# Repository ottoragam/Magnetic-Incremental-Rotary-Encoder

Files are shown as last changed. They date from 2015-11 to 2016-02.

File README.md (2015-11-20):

# Magnetic-Incremental-Rotary-Encoder

----------------------------------------------------------------------
Magnetic Incremental Rotary Encoder (c) by Gino Magarotto

Magnetic Incremental Rotary Encoder is licensed under a
Creative Commons Attribution-ShareAlike 3.0 Unported License.

You should have received a copy of the license along with this
work.  If not, see <http://creativecommons.org/licenses/by-sa/3.0/>.

----------------------------------------------------------------------

This project aims to provide a compact, easy to use, relatively high resolution and arguably cheap encoder. It uses the AS5040 magnetic rotary encoder IC from Austria Microsystems.

Project log on https://hackaday.io/project/8418-magnetic-incremental-rotary-encoder

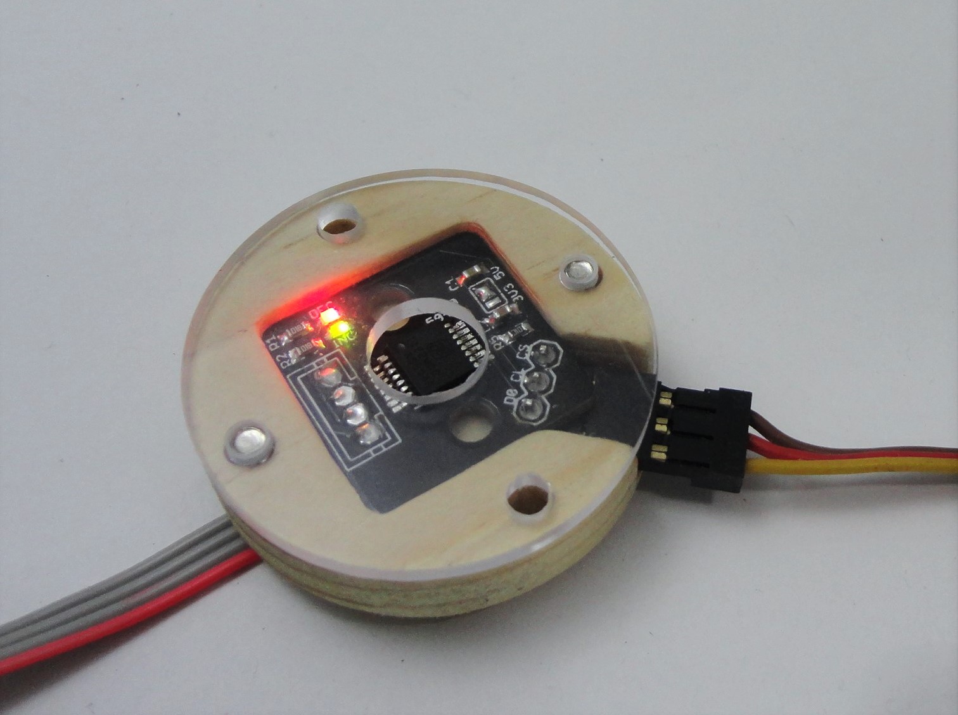
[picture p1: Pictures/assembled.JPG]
assembled


Included are.stl and .step files for the case, and .sch and .brd for the PCB.

The PCB is double sided and measures 20 x 20 mm. It could be home etched or manufactured using some low cost prototyping service. The case is designed to be milled, 3D printed or laser cut (the top part). A 3 mm or 1/8 in tap is also needed for threading two holes on the case cover.

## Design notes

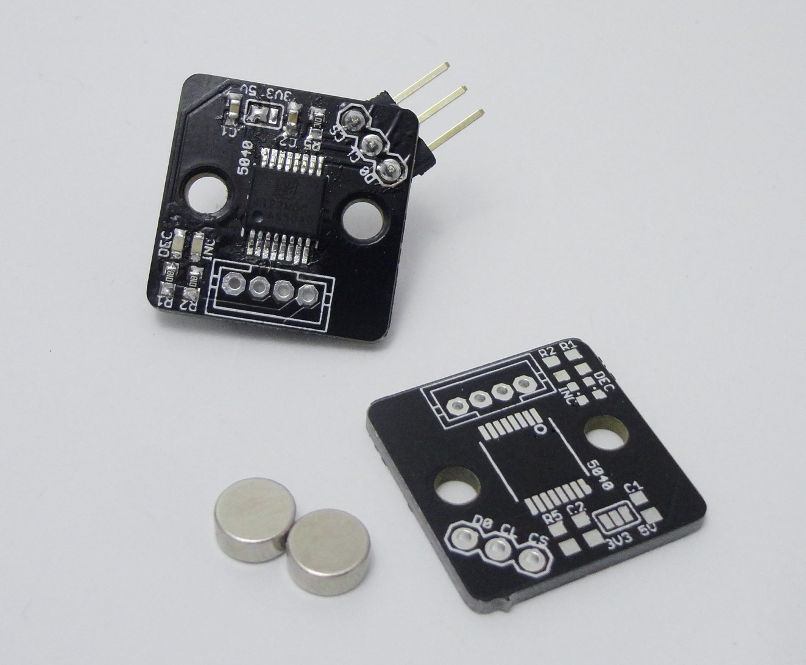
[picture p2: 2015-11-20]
Pictures/pcb1.JPG

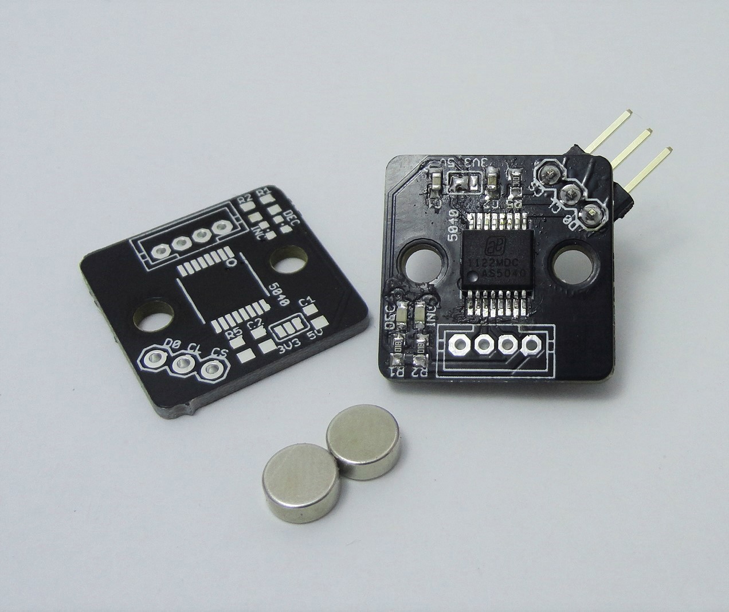
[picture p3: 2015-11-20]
Pictures/pcb2.JPG

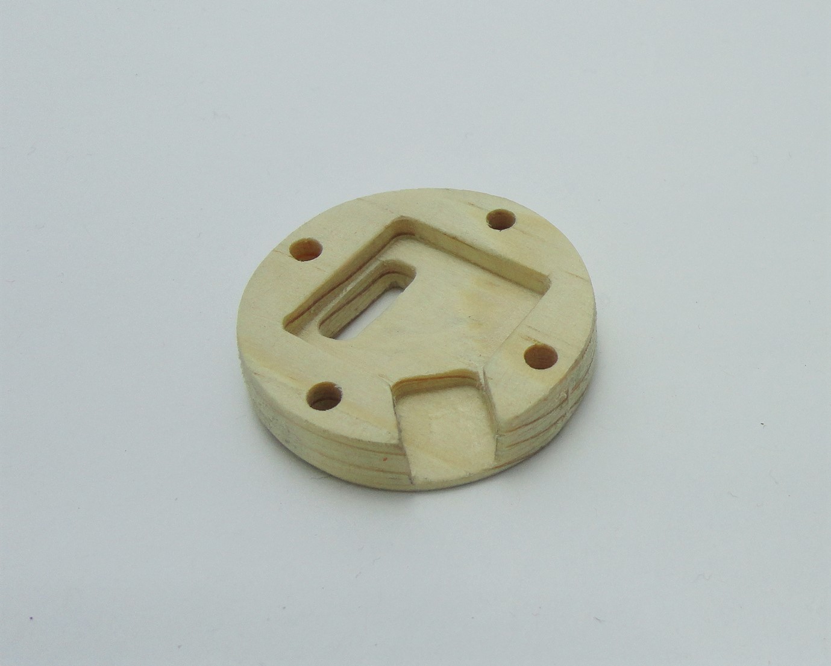
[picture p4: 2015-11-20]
Pictures/case_bottom.JPG

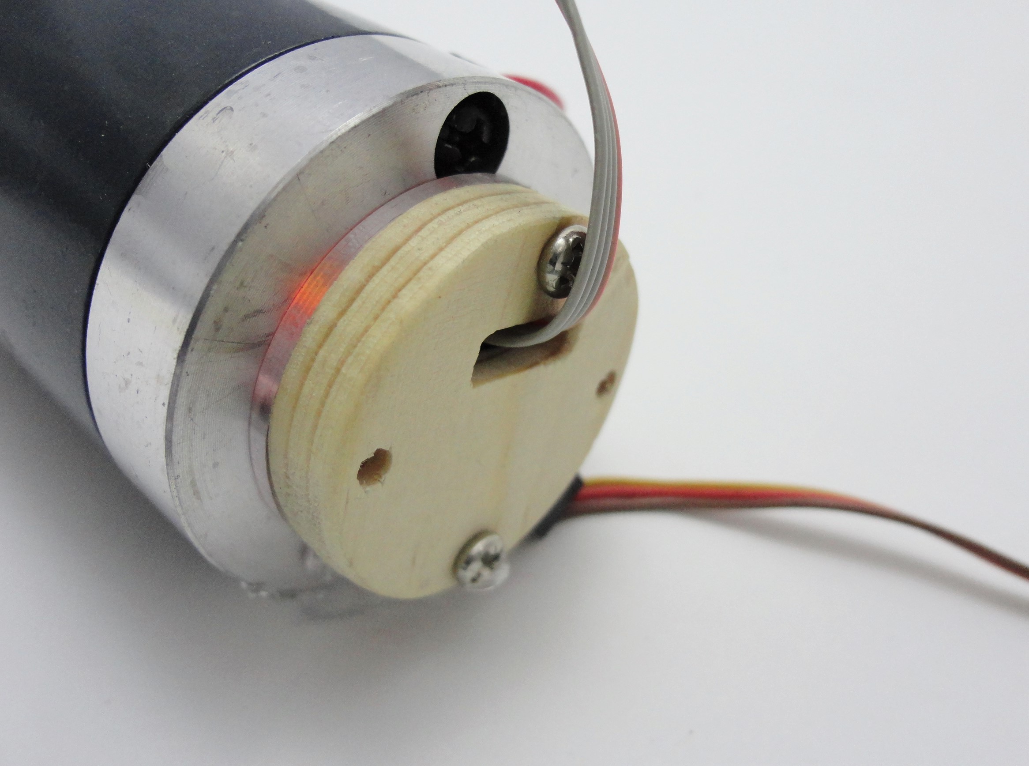
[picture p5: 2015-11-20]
Pictures/motor.JPG

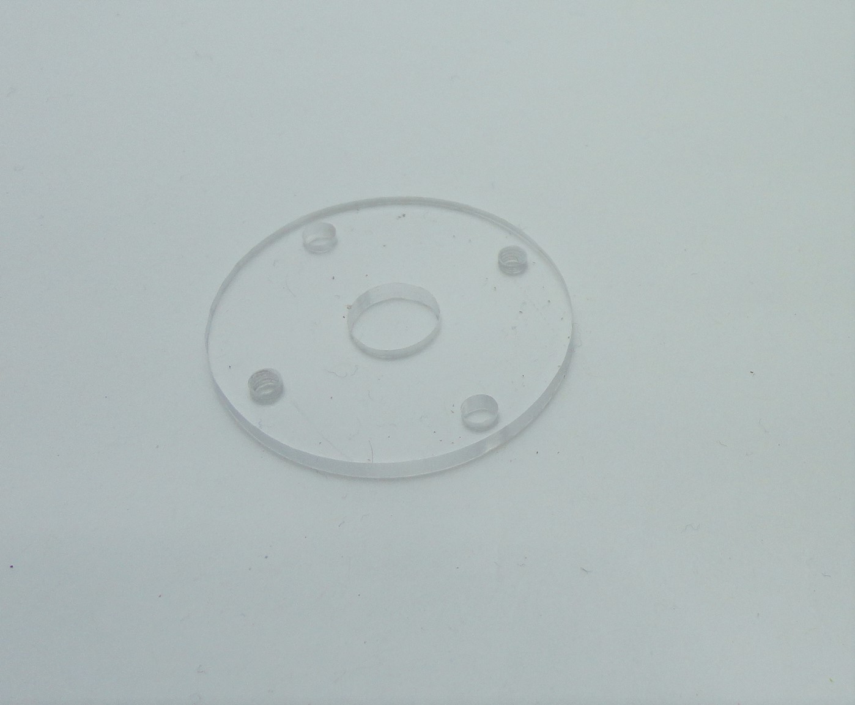
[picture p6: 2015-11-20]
Pictures/case top.JPG

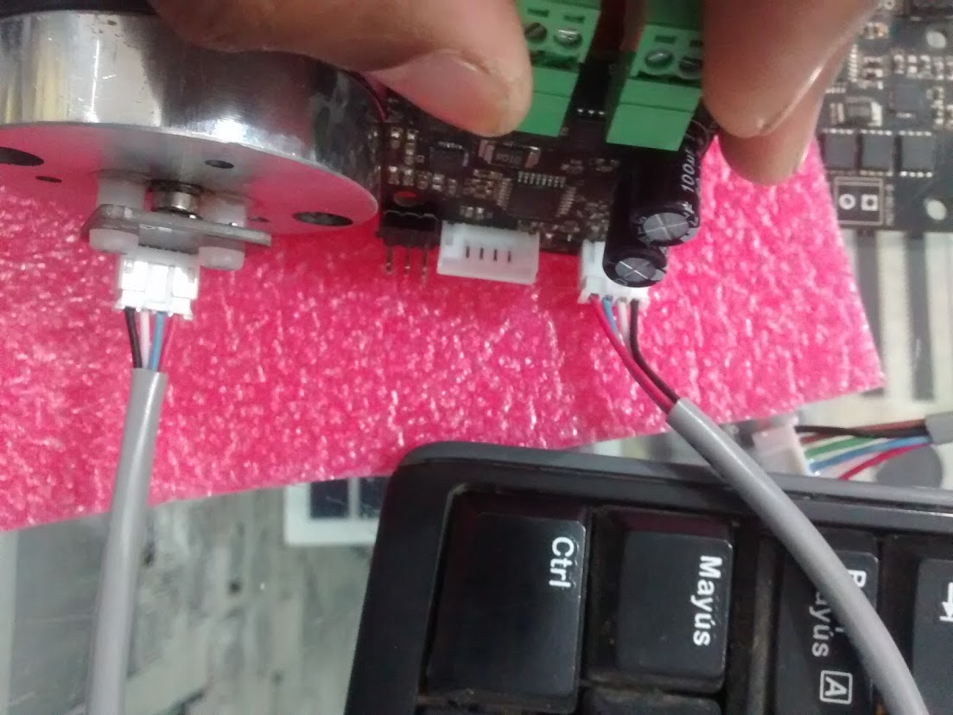
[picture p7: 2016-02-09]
Pictures/servo-drive.jpg

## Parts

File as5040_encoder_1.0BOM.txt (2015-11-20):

    1 × B4B-PH-K-S(LF)(SN) CONN HEADER PH TOP 4POS 2MM
    2 × SML-D12V8WT86 LED RED DIFFUSED 0603 SMD
    1 × 0.1 in male 90º header 3 pin header
    2 × CC0603KRX7R9BB104 CAP CER 0.1UF 50V X7R 0603
    1 × RC0603FR-0710KL RES SMD 10K OHM 1% 1/10W 0603
    2 × RC0603FR-071KL RES SMD 1K OHM 1% 1/10W 0603
    1 × AS5040-ASST IC ENCODER PROG 10-BIT 16-SSOP

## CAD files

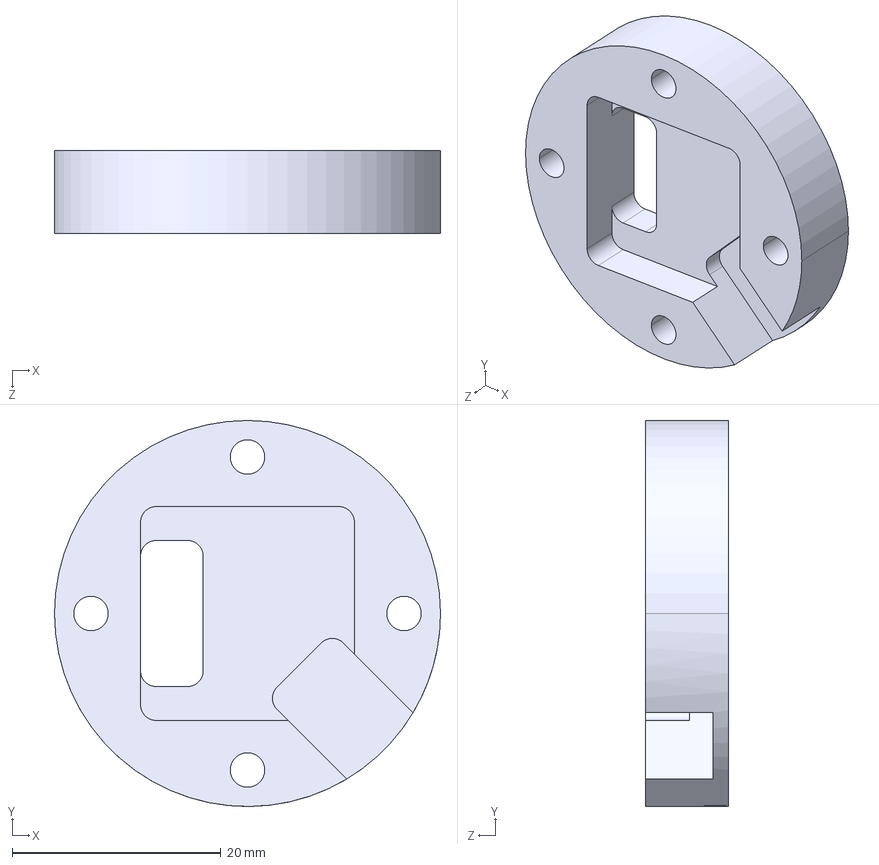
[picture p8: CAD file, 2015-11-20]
CAD/case_bottom.STEP
37.0 x 37.0 x 8.00 mm

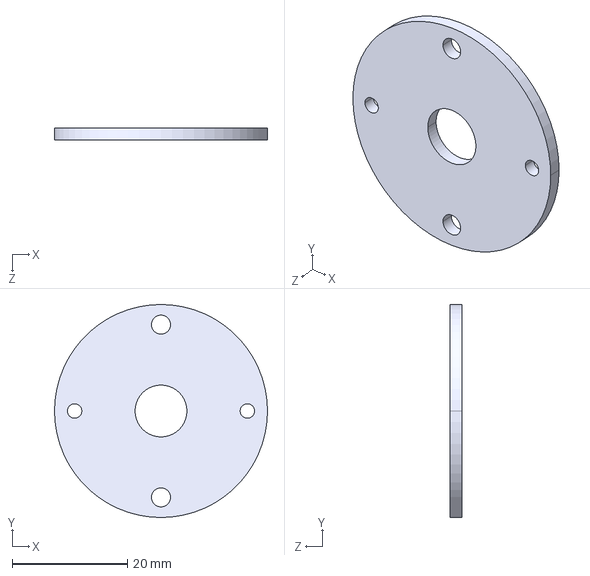
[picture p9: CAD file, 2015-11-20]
CAD/case_top.STEP
37.0 x 37.0 x 2.00 mm

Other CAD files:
CAD/case_bottom.STL
CAD/case_top.STL

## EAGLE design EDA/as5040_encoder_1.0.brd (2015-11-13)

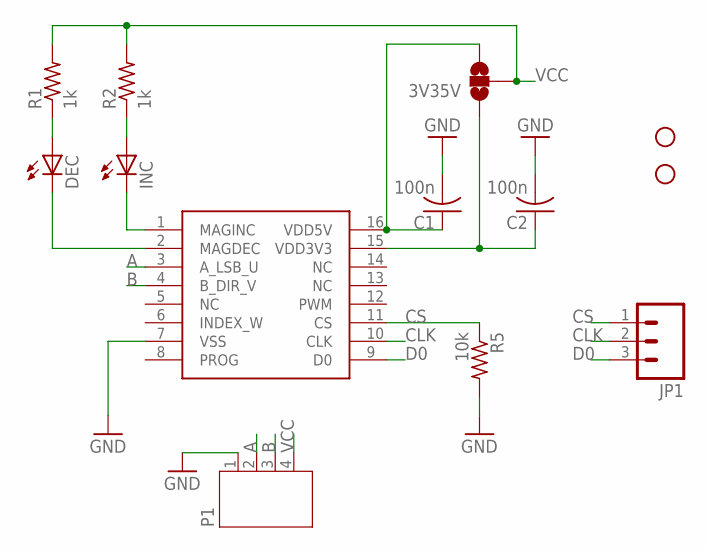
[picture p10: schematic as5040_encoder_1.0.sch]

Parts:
3V35V: SOLDERJUMPER_2WAYPASTE1&2&3; SJ_3_PASTE1&2&3
5040: AS5040; SSOP16
C1, C2: 100n; C0603K
DEC: LEDCHIPLED_0603; CHIPLED_0603
INC: LEDCHIPLED_0603; CHIPLED_0603
JP1: M03PTH; 1X03
P1: JST-PH4
R1, R2: 1k; R0603
R5: 10k; R0603
STANDOFF1, STANDOFF2: STAND-OFF

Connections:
A: 5040.3 (A_LSB_U), P1.2
B: 5040.4 (B_DIR_V), P1.3
CLK: 5040.10 (CLK), JP1.2
CS: 5040.11 (CS), JP1.1, R5.1
D0: 5040.9 (D0), JP1.3
GND: 5040.7 (VSS), C1.2, C2.2, P1.1, R5.2
unnamed: INC.A, R2.1
unnamed: DEC.A, R1.1
unnamed: 5040.1 (MAGINC), INC.C
unnamed: 5040.2 (MAGDEC), DEC.C
unnamed: 3V35V.3, 5040.16 (VDD5V), C1.1
unnamed: 3V35V.1, 5040.15 (VDD3V3), C2.1
VCC: 3V35V.2, P1.4, R1.2, R2.2

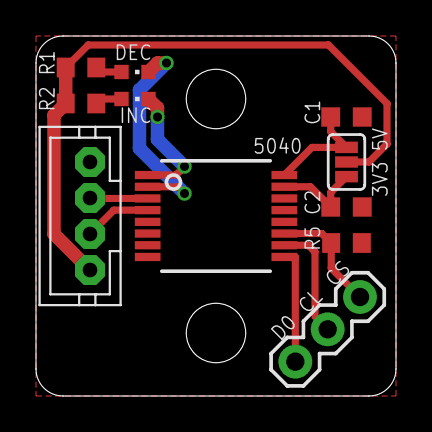
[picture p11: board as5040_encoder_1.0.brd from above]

Board: 2 copper layers, 20.0 x 20.0 mm, 13 parts (0 on the bottom side), 13 nets.

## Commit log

2015-11-13 EDA Files
    Eagle design iles or the PCB and gerbers
    [as5040_encoder_1.0.brd, as5040_encoder_1.0.sch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]
2015-11-13 EDA Files
    [as5040_encoder_1.0.brd, as5040_encoder_1.0.sch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]
2015-11-13 Revert "EDA Files"
    This reverts commit 6de166a53c72d63280062df4a804821b19d4f5fb.
    [as5040_encoder_1.0.brd, as5040_encoder_1.0.sch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]
2015-11-13 Datasheets, Drawings, BOM
2015-11-20 CAD designs
    [case_bottom.STEP, case_bottom.STL, case_top.STEP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]
2015-11-20 Added BOM

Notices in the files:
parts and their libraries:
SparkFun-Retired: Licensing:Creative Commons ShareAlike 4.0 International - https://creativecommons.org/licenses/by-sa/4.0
